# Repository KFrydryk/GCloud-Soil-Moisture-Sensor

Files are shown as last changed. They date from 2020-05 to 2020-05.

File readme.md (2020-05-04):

# Google Cloud Soil Moisture Sensor

This is a home project and an exercise on using Cloud solutions in IoT. 

The project uses a generic soil moisture sensor and a photoresistor with ESP8266 and complementary devices (resistors, buttons, voltage regulator and some pin headers).

[*Results can be seen here!*](https://datastudio.google.com/reporting/f9fdeeb2-1fdc-4f80-99da-87816e4d7d12)

# How does it work?

The data is from the sensor is gathered as analog value and mapped to 0-100% range. ESP8266s analog in is rated for 0-1V only so the reading has to be transformed via a simple voltage divider.
Photoresistor value is mapped to binary values of 0 (dark) and 100 (light) as ESP8266 has only 1 analog input. To make it more consistent, the value is gathered form a variable voltage divider and reading routine sets the input pin value high before the actual reading process. It guarantees same voltage threshold for low/high exposition transitions despite the input hysteresis.
Data is filtered by a simple moving average filter and translated into JSON format, which can be sent using MQTT protocol to Google IoT service.
IoT routine sets off a google Cloud Function service to parse the JSON data and insert it into BigQuery database.
For graphical output Google Datastudio is used. Data is obtained using automated SQL query every hour or on users demand.

# PCB
PCB was designed in Autocad EAGLE, all of the necessary files should be updated in [Eagle_files folder](https://github.com/KFrydryk/GCloud-Soil-Moisture-Sensor/tree/master/Eagle_files)

# Schematic

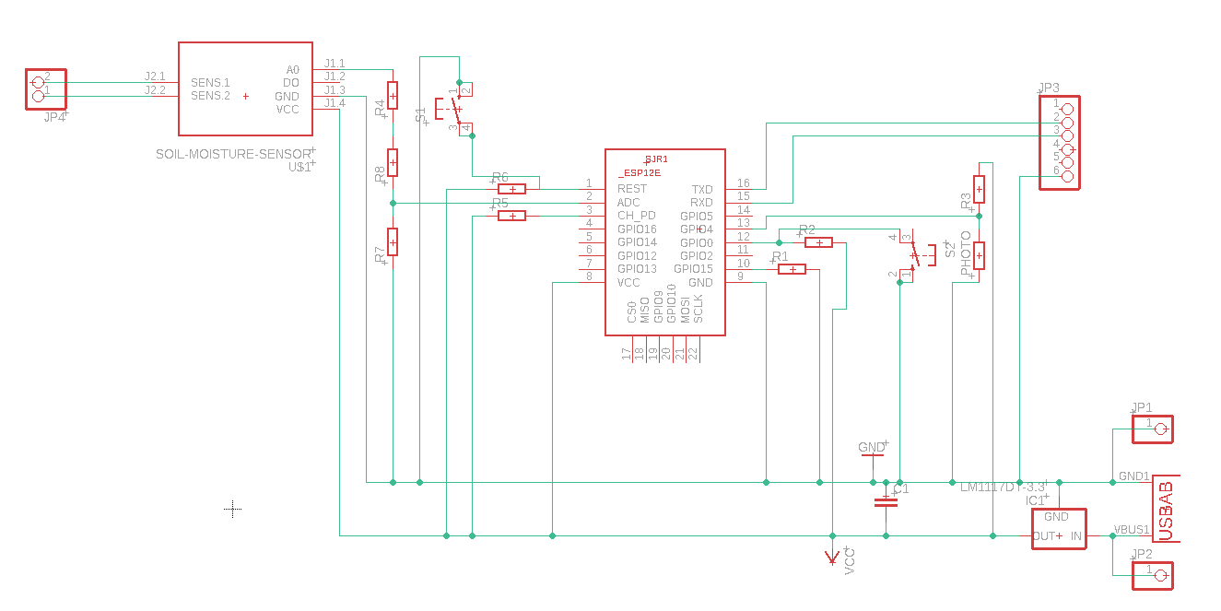
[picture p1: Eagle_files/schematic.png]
schematic Schematic


# Board

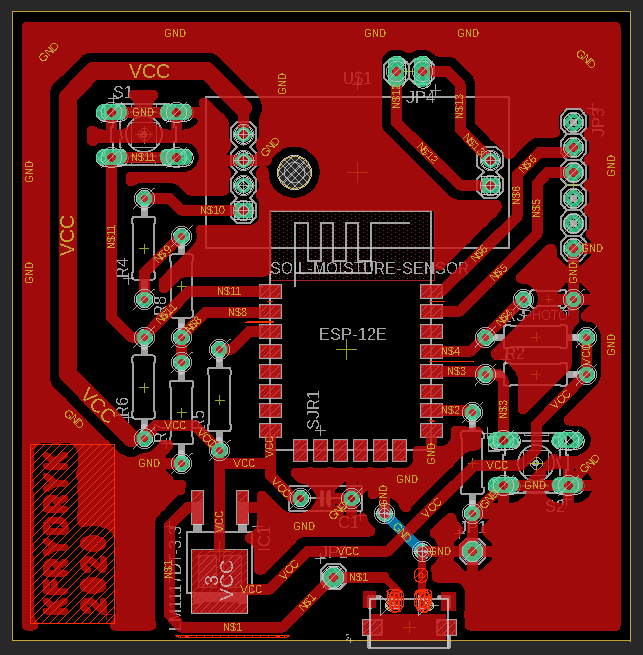
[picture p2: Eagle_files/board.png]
Board


# Photo

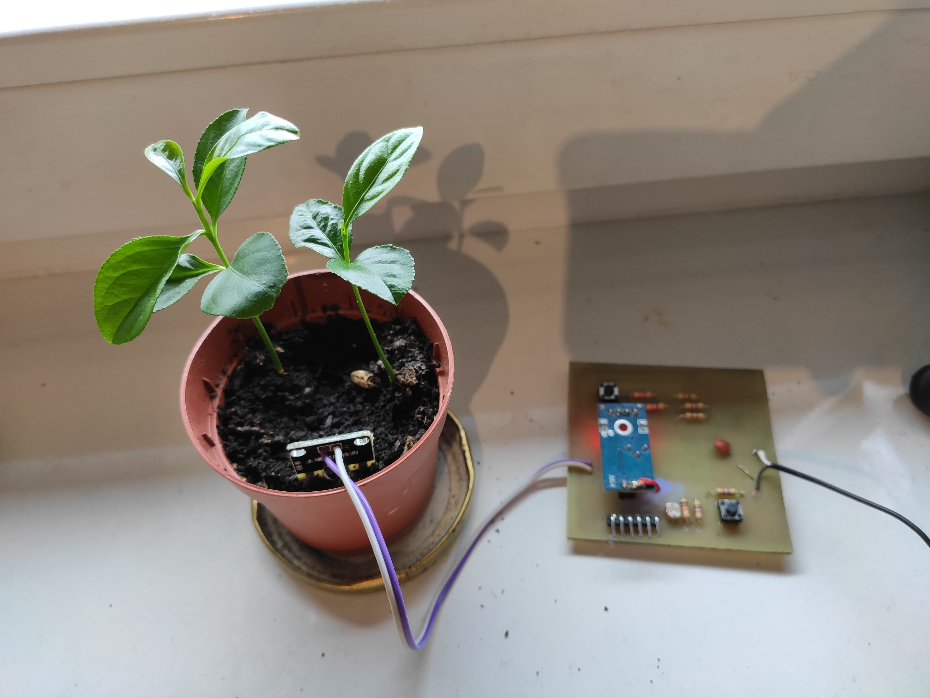
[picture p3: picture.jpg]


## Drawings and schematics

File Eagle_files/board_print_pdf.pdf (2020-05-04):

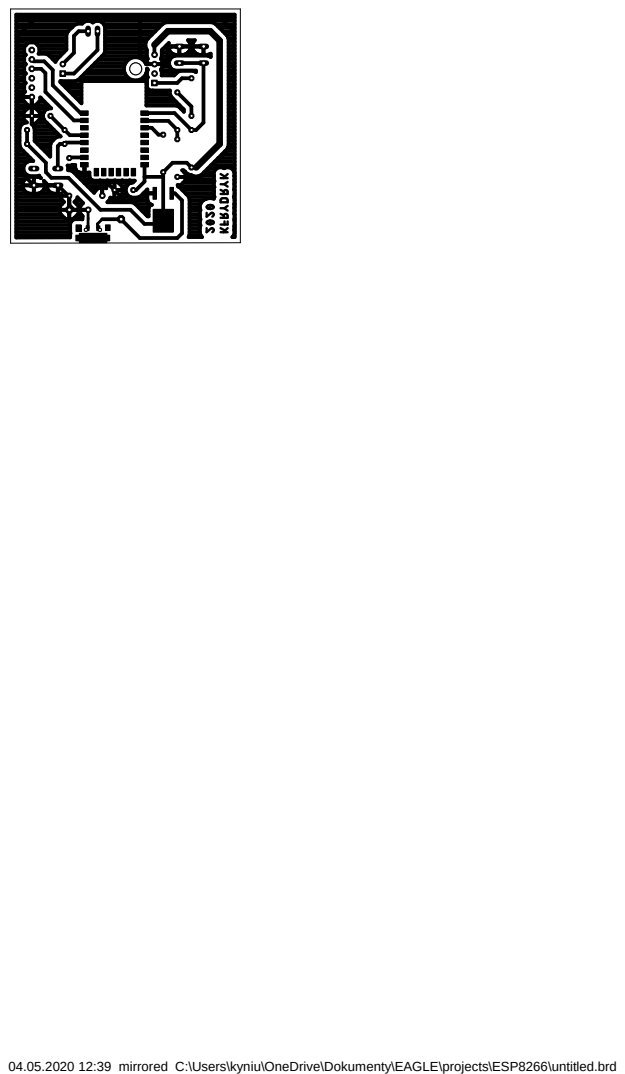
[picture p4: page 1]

04.05.2020 12:39 mirrored C:\Users\kyniu\OneDrive\Dokumenty\EAGLE\projects\ESP8266\untitled.brd

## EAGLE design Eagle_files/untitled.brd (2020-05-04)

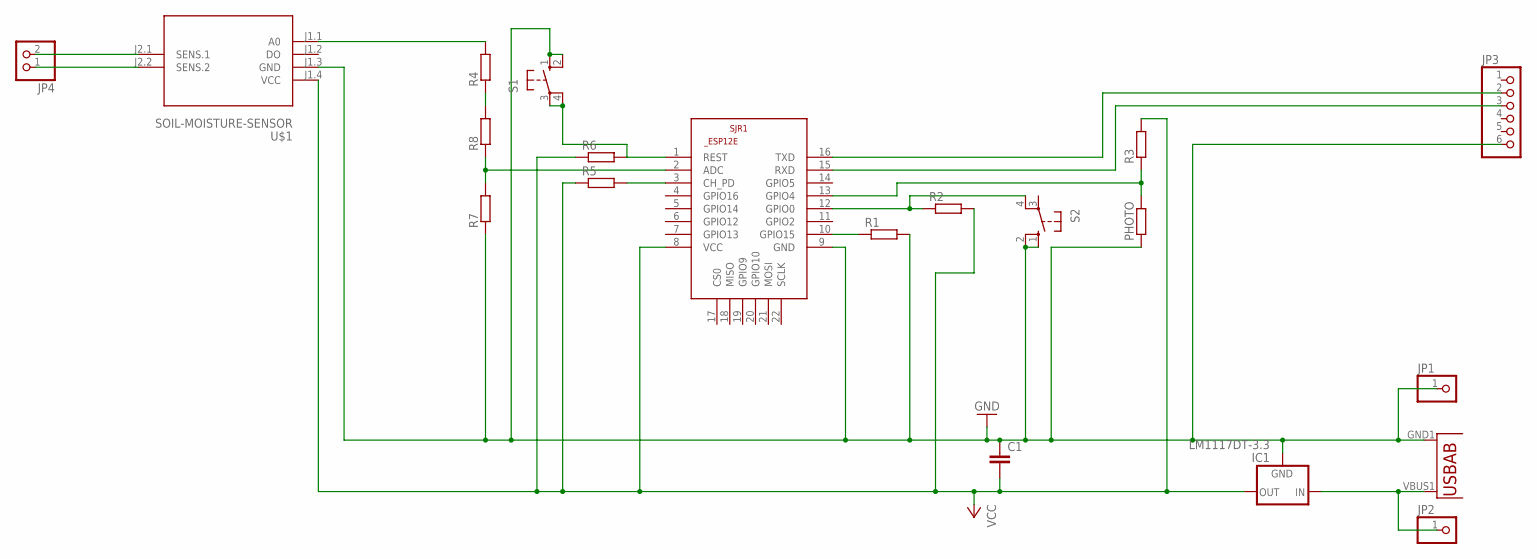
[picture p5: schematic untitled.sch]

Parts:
C1: C-EU050-025X075; C050-025X075
IC1: LM1117DT-3.3; TO252
JP1, JP2: PINHD-1X1; 1X01
JP3: PINHD-1X6; 1X06
JP4: PINHD-1X2; 1X02
PHOTO: R-EU_0204/5; 0204/5
R1, R2, R3, R4, R5, R6, R7, R8: R-EU_0207/10; 0207/10
S1, S2: 10-XX; B3F-10XX
SJR1: ESP8266-12EESP12E; ESP8266-ESP12E
U1: USB""; USB-MICRO-SMD
U$1: SOIL-MOISTURE-SENSOR

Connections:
GND: C1.1, IC1.1 (GND), JP1.1, JP3.6, PHOTO.1, R1.2, R7.1, S1.1 (S), S1.2 (S1), S2.1 (S), S2.2 (S1), SJR1.9 (GND), U1.GND1 (GND), U$1.J1.3 (GND)
unnamed: IC1.2 (IN), JP2.1, U1.VBUS1 (VBUS)
unnamed: R1.1, SJR1.10 (GPIO15)
unnamed: R2.1, S2.4 (P1), SJR1.12 (GPIO0)
unnamed: PHOTO.2, R3.1, SJR1.13 (GPIO4)
unnamed: JP3.3, SJR1.15 (RXD)
unnamed: JP3.2, SJR1.16 (TXD)
unnamed: R5.2, SJR1.3 (CH_PD)
unnamed: R7.2, R8.1, SJR1.2 (ADC)
unnamed: R4.1, R8.2
unnamed: R4.2, U$1.J1.1 (A0)
unnamed: R6.2, S1.3, S1.4 (P1), SJR1.1 (REST)
unnamed: JP4.2, U$1.J2.1 (SENS.1)
unnamed: JP4.1, U$1.J2.2 (SENS.2)
VCC: C1.2, IC1.3 (OUT), R2.2, R3.2, R5.1, R6.1, SJR1.8 (VCC), U$1.J1.4 (VCC)

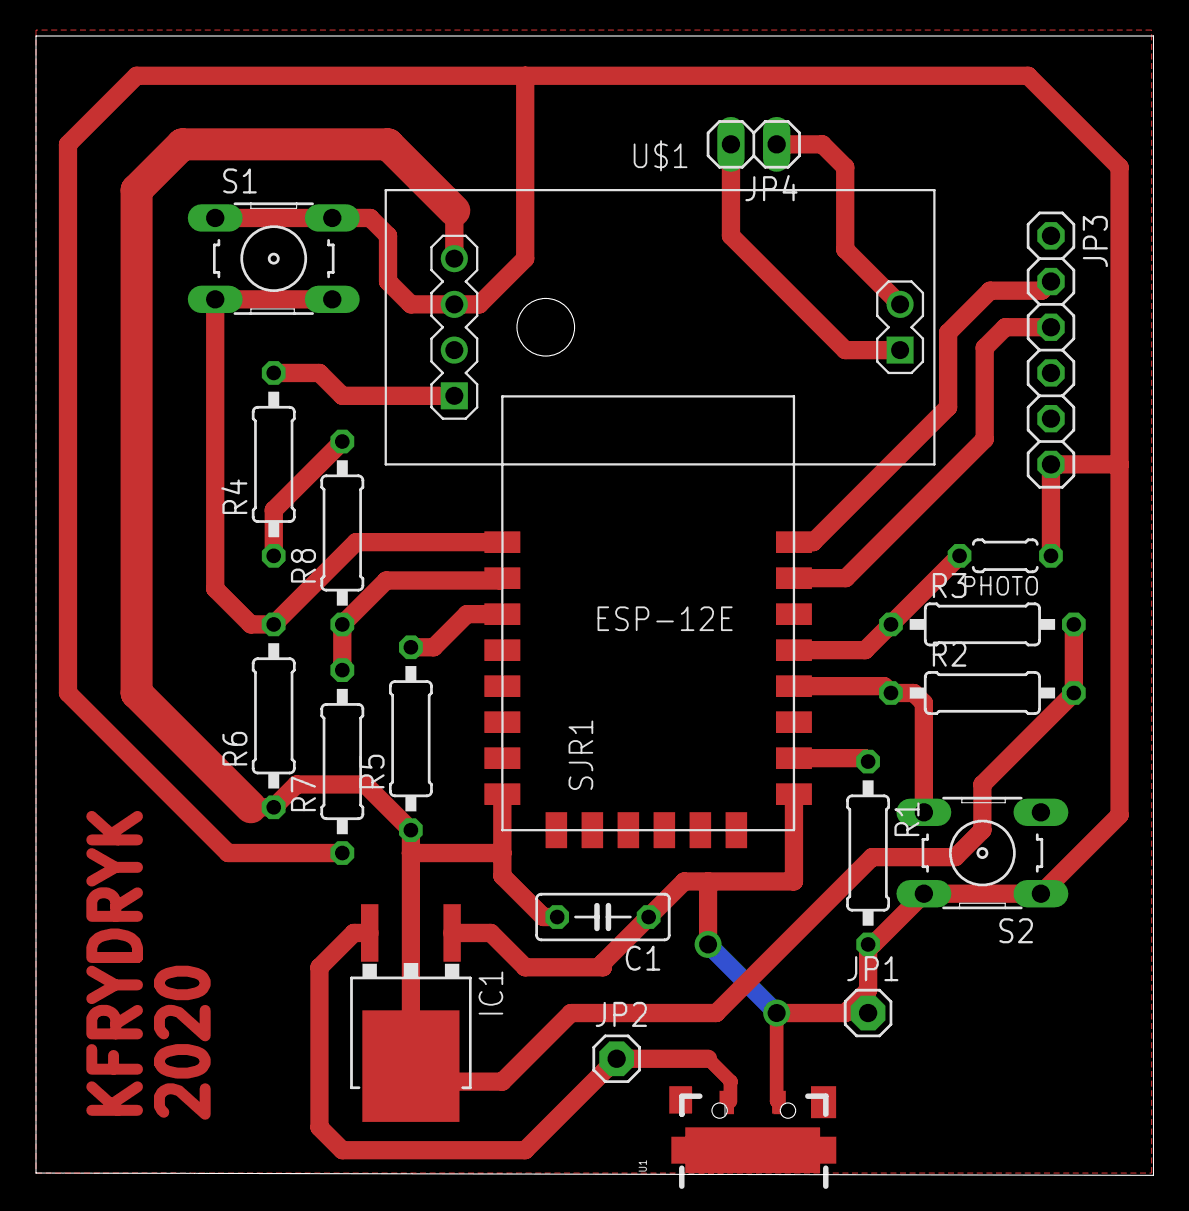
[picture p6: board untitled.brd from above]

Board: 2 copper layers, 62.1 x 63.3 mm, 20 parts (0 on the bottom side), 15 nets.

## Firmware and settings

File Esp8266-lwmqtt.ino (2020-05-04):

/******************************************************************************
 * Copyright 2018 Google
 * Licensed under the Apache License, Version 2.0 (the "License");
 * you may not use this file except in compliance with the License.
 * You may obtain a copy of the License at
 *
 *    http://www.apache.org/licenses/LICENSE-2.0
 *
 * Unless required by applicable law or agreed to in writing, software
 * distributed under the License is distributed on an "AS IS" BASIS,
 * WITHOUT WARRANTIES OR CONDITIONS OF ANY KIND, either express or implied.
 * See the License for the specific language governing permissions and
 * limitations under the License.
 *****************************************************************************/
#include <CloudIoTCore.h>
#include "esp8266_mqtt.h"

#include <ArduinoJson.h>
#include "movingAvg.h"

#ifndef LED_BUILTIN
#define LED_BUILTIN 13
#endif


StaticJsonDocument<200> JsonDoc;
movingAvg smoothSensor(100);

void setup()
{
  // put your setup code here, to run once:
  Serial.begin(115200);
  setupCloudIoT(); // Creates globals for MQTT
  pinMode(LED_BUILTIN, OUTPUT);
  smoothSensor.begin();
}


char JsonSend[100];
unsigned long lastMillis = 0;

void loop()
{
  mqtt->loop();
  smoothSensor.reading(analogRead(A0));
  delay(10); // <- fixes some issues with WiFi stability
  Serial.println(analogRead(A0));
  if (!mqttClient->connected())
  {
    ESP.wdtDisable();
    connect();
    ESP.wdtEnable(0);
  }

  // TODO: Replace with your code here
  if (millis() - lastMillis > 60000)
  {
    pinMode(4, OUTPUT);
    digitalWrite(4, HIGH);
    pinMode(4, INPUT);
    JsonDoc["Light"] = 100*(1-digitalRead(4));
    JsonDoc["id"] = 1;
    JsonDoc["time"] = time(nullptr);
    JsonDoc["Humidity"] = map((1023-smoothSensor.getAvg()), 0, 1024, 0, 100);
    serializeJsonPretty(JsonDoc, JsonSend);
    lastMillis = millis();
 
    Serial.println(JsonSend);
    publishTelemetry(JsonSend);
  }
}

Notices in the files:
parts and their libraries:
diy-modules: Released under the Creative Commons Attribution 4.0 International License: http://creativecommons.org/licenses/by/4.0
